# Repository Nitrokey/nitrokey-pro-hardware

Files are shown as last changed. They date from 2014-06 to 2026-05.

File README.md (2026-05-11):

Nitrokey Pro PCB Design
===================================================

Nitrokey Pro is a USB 32-bit computer with STM32F103 processor and
an OpenPGP smart card. It has a minimalistic design, the MCU is running
at 72MHz, and it has a SWD port for main flash ROM update.

This is Nitrokey PCB design for KiCAD, based on Niibe
Yutaka's Flying Stone Tiny 01 (FST-01).

Files
=====

    README:           This file
    BOM.csv           Part list including Digikey product number.
    ChangeLog:        History of this project
    cryptostick.pro:  Project file of KiCAD
    cryptostick.sch:  Schematic
    cryptostick.cmp:  Component
    cryptostick.net:  Netlist
    cryptostick.stf:  Component and Module
    cryptostick.brd:  PCB design
    library:          schematic library
    module:           footprint modules for PCB
    fabrication:      Gerber files of the PCB
    datasheet:        Datasheets of parts

Note that files under datasheet directory is copyrighted by vendors.

Revisions
=========

| Revision | MCU |
|---|---|
| 1 | ST STM32F103TB |
| 2 | ST STM32F103TB |
| 3 | ST STM32F103TB |
| 4 | ST 32F103B7 |
| 5 | GigaDevice GD32F103CB |
| 6 | ST STM32F103TB |

Terms and conditions
====================

This work is based on Niibe Yutaka's Flying Stone Tiny 01 (FST-01) PCB Design.

I would like to ask users to keep the design as "Open Hardware".  See
the page for the definition of "Open Hardware":
http://www.opencollector.org/Whyfree/open_hardware.html

Nevertheless, schematic design is distributed under Creative Commons
Attribution 3.0 Unported License (CC BY 3.0).  See:
http://creativecommons.org/licenses/by/3.0/

Schematic design can be used for any purpose and you don't need to
open your modifications to my design.

For PCB, it is distributed under Creative Commons
Attribution-ShareAlike 3.0 Unported (CC BY-SA 3.0).  See:
http://creativecommons.org/licenses/by-sa/3.0/

External modules
================

For module/SMT_CAP.mod and module/SMT_RES.mod, module drawings are
copied from w_smd_cap.mod and w_smd_resistors.mod by W.Lain.  Files
are available at:
http://smisioto.no-ip.org/elettronica/kicad/kicad-en.htm

Its copyright notice is like following:

> Kicad Library by W. Lain - kcswalter@member.fsf.org

> This library is released under the terms of the Creative Commons
license v3.0, Attribution-Share Alike.

> The author holds no responsibility for any damage that can be caused
by the usage of this library. You are however welcome to report any
error or discrepance to the author, provided that you give also the
correct information and its source (i.e. the correct datasheet).

> **Note that the author used publicly available data sheets from many
different companies, and that package dimensions, pin numeration and
schematic symbols may vary slightly between companies.**

Flashing
========

For instructions on flashing the device please have a look at the [Nitrokey Pro firmware
repo](https://github.com/Nitrokey/nitrokey-pro-firmware).

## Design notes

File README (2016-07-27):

Crypto Stick v1 PCB Design

							    Version 0.1
							     2014-01-17
						               Jan Suhr

Introduction
==============

Crypto Stick is a USB 32-bit computer with STM32F103 processor and
an OpenPGP smart card. It has a minimalistic design, the MCU is running
at 72MHz, and it has a SWD port for main flash ROM update.

This is Crypto Stick v1 PCB design for KiCAD, based on Niibe
Yutaka's Flying Stone Tiny 01 (FST-01).

Files
=====

    README:           This file
    BOM.csv           Part list including Digikey product number.
    ChangeLog:        History of this project
    cryptostick.pro:  Project file of KiCAD
    cryptostick.sch:  Schematic
    cryptostick.cmp:  Component
    cryptostick.net:  Netlist
    cryptostick.stf:  Component and Module
    cryptostick.brd:  PCB design
    library:          schematic library
    module:           footprint modules for PCB
    gerber:           Gerber files of the PCB
    datasheet:        Datasheets of parts

Note that files under datasheet directory is copyrighted by vendors.

Terms and conditions
====================

This work is based on Niibe Yutaka's Flying Stone Tiny 01 (FST-01) PCB Design.

I would like to ask users to keep the design as "Open Hardware".  See
the page for the definition of "Open Hardware":

    http://www.opencollector.org/Whyfree/open_hardware.html

Nevertheless, schematic design is distributed under Creative Commons
Attribution 3.0 Unported License (CC BY 3.0).  See:

    http://creativecommons.org/licenses/by/3.0/

Schematic design can be used for any purpose and you don't need to
open your modifications to my design.

For PCB, it is distributed under Creative Commons
Attribution-ShareAlike 3.0 Unported (CC BY-SA 3.0).  See:

    http://creativecommons.org/licenses/by-sa/3.0/

External modules
================

For module/SMT_CAP.mod and module/SMT_RES.mod, module drawings are
copied from w_smd_cap.mod and w_smd_resistors.mod by W.Lain.  Files
are available at:

   http://smisioto.no-ip.org/elettronica/kicad/kicad-en.htm

Its copyright notice is like following:
---------------------------------------------------------------------
Kicad Library by W. Lain - kcswalter@member.fsf.org

This library is released under the terms of the Creative Commons
license v3.0, Attribution-Share Alike.

The author holds no responsibility for any damage that can be caused
by the usage of this library. You are however welcome to report any
error or discrepance to the author, provided that you give also the
correct information and its source (i.e. the correct datasheet).

Note that the author used publicly available data sheets from many
different companies, and that package dimensions, pin numeration and
schematic symbols may vary slightly between companies.
---------------------------------------------------------------------

Flashing
========

This hardware can be flashed in two different ways:

* SWD protocol requires a separate programmer such as the ST-Link V2 (or cheaper clones). The SWD port or the Nitrokey PCB are the four blank contact points. You can either solder four wires or build your own adapter (see directory cs_pogo_adapter).

* A bit easier would be to use DFU. It requires a serial/TTL port (perhaps you need a serial/TTL-USB adapter) and a simple adapter. The DFU port is routed to the USB plug. Your adapter should consist of a USB socket which four pins are connected to your serial/TTL connector. The pinout is as follows.

Nitrokey USB Plug <-> Serial/TTL adapter

Pin 1, VCC <-> VCC
Pin 2, D-  <-> TX
Pin 3, D+  <-> RX
Pin 4, GND <-> GND

This diagram represents the pinout of the USB socket which you are going to solder:

  ################### 
  #                 # 
  # ############### # 
  #                 # 
  #                 # 
  ################### 
     #   #   #   #   
     #   #   #   #    

     1   2   3   4

To flash the firmware you need to bridge the two contact holes (e.g. with a wire) and only then connect (and power) the PCB to your adapter. The bridge triggers the hardware to boot into DFU mode. You may use [STM32 Flash Loader Demonstrator](http://www.st.com/content/st_com/en/products/development-tools/software-development-tools/stm32-software-development-tools/stm32-programmers/flasher-stm32.html) (Windows only) or the open source command line tool [stm32flash](http://stm32flash.sourceforge.net).

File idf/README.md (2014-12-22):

Creating IDF libraries
======================

Two files are needed to create an IDF library. An .emn and an .emp. 

* .emn: Holds information about the PCB board, the drilled holes and the placement of the parts.
* .emp: Holds information about each class of a component that is used at .emn placement.

To create a 3D model of the IDF library, you can open the .emn file using FreeCAD. Then you can save the 3D models as a .FCStd file.

The procedure of creating and manipulating an IDF library is explained below (per project).

Creating the .emp
-----------------
	The .emp file consists of a header section at the beginning. This sections is followed by electrical sections. Each electrical section has the outline info as a series of points in a 2D plane, and a height value. The outline must be a closed curve, thus you need to place twice the point that you started, once at the beginning and once at the end of the section (returning to starting point).
	If it is a rectangular outline, use point (0,0) as the center of it.

Creating the .emn
-----------------
	The .emn file consists of a header section, a board section, a drilled_holes section and a placement section. The board section describes the boad outline and height. The placement section is a series of placement declarations, each one declaring the type of the component (from .emp file), a placeholder name,  the positioning at the 3D plane, a rotation factor and the side of the board that is to be placed (top/bottom)

Nitrokey Pro
------------
	For Nitrokey Pro, you have to open the .kicad_pcb file. There is a section that lists all the modules. Each module has the component type (BOM file), the placeholder name (emp placement). the positioning and rotation (emp placement). 

You have to manually create/edit the .emp file consulting the BOM and manuals.
You have to manually create/edit the .emn file consulting the .kicad_pcb file for the placement coordinates.

*Note 1: Depending on the orientation of each component at it's electrical section, you may need to use rotation to match the real design.*

*Note 2: Depending on the side that the component is placed, you may have to calculate some offsets because the coords seems to be mirrored on the other side (and you have to mirror them again so that it aligns).*

Nitrokey Storage
----------------
	For Nitrokey Storage, you have to use DesignSpark. First you export the pcb design as a set of .idl and .idf files [3](without the height adjusting, see next par.) . Rename .idl to .emp and .idf to .emn (they are essentially the same format).
	You will have to manually edit the .emp file to include all the electrical sections (consulting the BOM, manualls and naming of the components from the .emn file).  The .emn file doen't need any changes.

Notes (on Storage):
1) Right now the height of the short capacitors and resistors is not accurate. An approximation is used instead (worst case found from the family of each component).
2) For some components the length does not include the extra soldering area.
3) Electrical sections for the R0603, C0603, C0603K and C1206 need to be rewritten with (0,0) as their center. Also their orientation at the placement section need to be changed appropriatelly. 

For both devices
----------------
	Create a second module to model USB.

Useful Links
------------
[1] https://www.simplifiedsolutionsinc.com/images/idf_v30_spec.pdf
[2] https://sourceforge.net/projects/kicad-3d/
[3] http://www.rs-online.com/designspark/electronics/eng/tutorial/exporting-designs-from-designspark-pcb-to-mechanical-cad

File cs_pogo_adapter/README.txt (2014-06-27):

J8 and J9 are different types of pads used on different target PCBs. They are all connected together to make testing easier.

R1 and R2 are required depending on whether you use Versaloon or ST-Link programmer.

R1 is used to power the target device when using ST-Link. ST-Link doesn't provide power to the target board normally, but it has 3.3V on pin 19 of the JTAG connector (which is normally not connected on the target board).

R2 is used to power the target device when using Versaloon. I think Versaloon can power the target through pin 1 of the JTAG connector, but I'm not sure.

J4 and J7 are obsolete and should be removed.

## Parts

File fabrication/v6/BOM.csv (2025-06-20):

Id | Designator | Package | Quantity | Designation | Digikey Part Number | Digikey URL
1 | JP1 | boot | 1 | JUMPER | n.a.
2 | P1 | SIL-2-2 | 1 | CONN_4 | n.a.
3 | C3,C7,C6,C5,C4,C8 | c_0402 | 6 | 0.1uF | No tantalum, tolerance 20%, temperature -20 to +70 °C. | http://www.digikey.com/product-detail/en/C1005X7R1C104M050BC/445-4953-1-ND/2093567
4 | R1,R2 | r_0402 | 2 | 510 | 1% tolerance, temperature -20 to +70 °C. | http://www.digikey.com/product-detail/en/RC0402FR-07510RL/311-510LRCT-ND/729579
5 | C1,C2 | c_0402 | 2 | 27pF | No tantalum, tolerance 20%, temperature -20 to +70 °C. | http://www.digikey.com/product-detail/en/C1005C0G1H270J050BA/445-1240-1-ND/567721
6 | C9,C11 | c_0402 | 2 | 4.7uF | No tantalum, tolerance 20%, temperature -20 to +70 °C. | http://www.digikey.com/product-detail/en/C1005X5R1A475M050BC/445-8023-1-ND/2792141
7 | U2 | TSOT23-5 | 1 | CAT6217-330 | 576-2835-1-ND or ADP121-AUJZ33R7CT-ND | http://www.digikey.com/product-detail/en/MIC5265-3.3YD5%20TR/576-2835-1-ND/1821995
8 | U1 | QFN36 | 1 | STM32F103TB | 497-11534-ND | http://www.digikey.com/product-search/en?vendor=0&keywords=497-11534-ND
9 | X1 | ABM8G | 1 | 12MHz | 535-10283-1-ND | http://www.digikey.com/product-detail/en/ABM8G-12.000MHZ-B4Y-T/535-10283-1-ND/2218096
10 | R3,R4 | c_0402 | 2 | 10k | 1% tolerance, temperature -20 to +70 °C. | http://www.digikey.com/product-detail/en/RC0402FR-0710KL/311-10.0KLRCT-ND/729470
11 | C10 | c_0402 | 1 | 0.01uF | No tantalum, tolerance 20%, temperature -20 to +70 °C. | http://www.digikey.com/product-detail/en/C1005X7R1E103K050BB/445-1260-1-ND/567737
12 | U3 | SOT-553 | 1 | DF5A5.6JE | DF5A5.6JELMCT-ND | https://www.digikey.com/products/en?keywords=DF5A5.6JELMCT-ND
13 | J2 | USB-A-PLUG | 1 | USB_A | WM3983TR-ND | http://www.digikey.com/product-detail/en/0480372200/WM3983CT-ND/2421836
14 | D1 | KPHBM-2012SURKCGKC | 1 | DUAL_LED | element14.com 1686079RL | http://www.digikey.com/product-detail/en/APHBM2012SURKCGKC/754-1093-1-ND/1747810
15 | J1 | Molex 0786463001 | 1 | SIM_JACKET | WM9364CT-ND | http://www.digikey.com/product-detail/en/0786463001/WM9364CT-ND/3770350
16 | R7 | r_0402 | 1 | 1.5k | 311-1.50KLRCT-ND | https://www.digikey.com/product-detail/en/yageo/RC0402FR-071K5L/311-1.50KLRCT-ND/729466
17 | R5,R6 | r_0402 | 2 | 22 | 311-22.0LRCT-ND | https://www.digikey.com/product-detail/en/yageo/RC0402FR-0722RL/311-22.0LRCT-ND/729509
18 | R8 | r_0402 | 1 | 20k | 311-20.0KLRCT-ND | https://www.digikey.de/de/products/detail/yageo/RC0402FR-0720KL/726557

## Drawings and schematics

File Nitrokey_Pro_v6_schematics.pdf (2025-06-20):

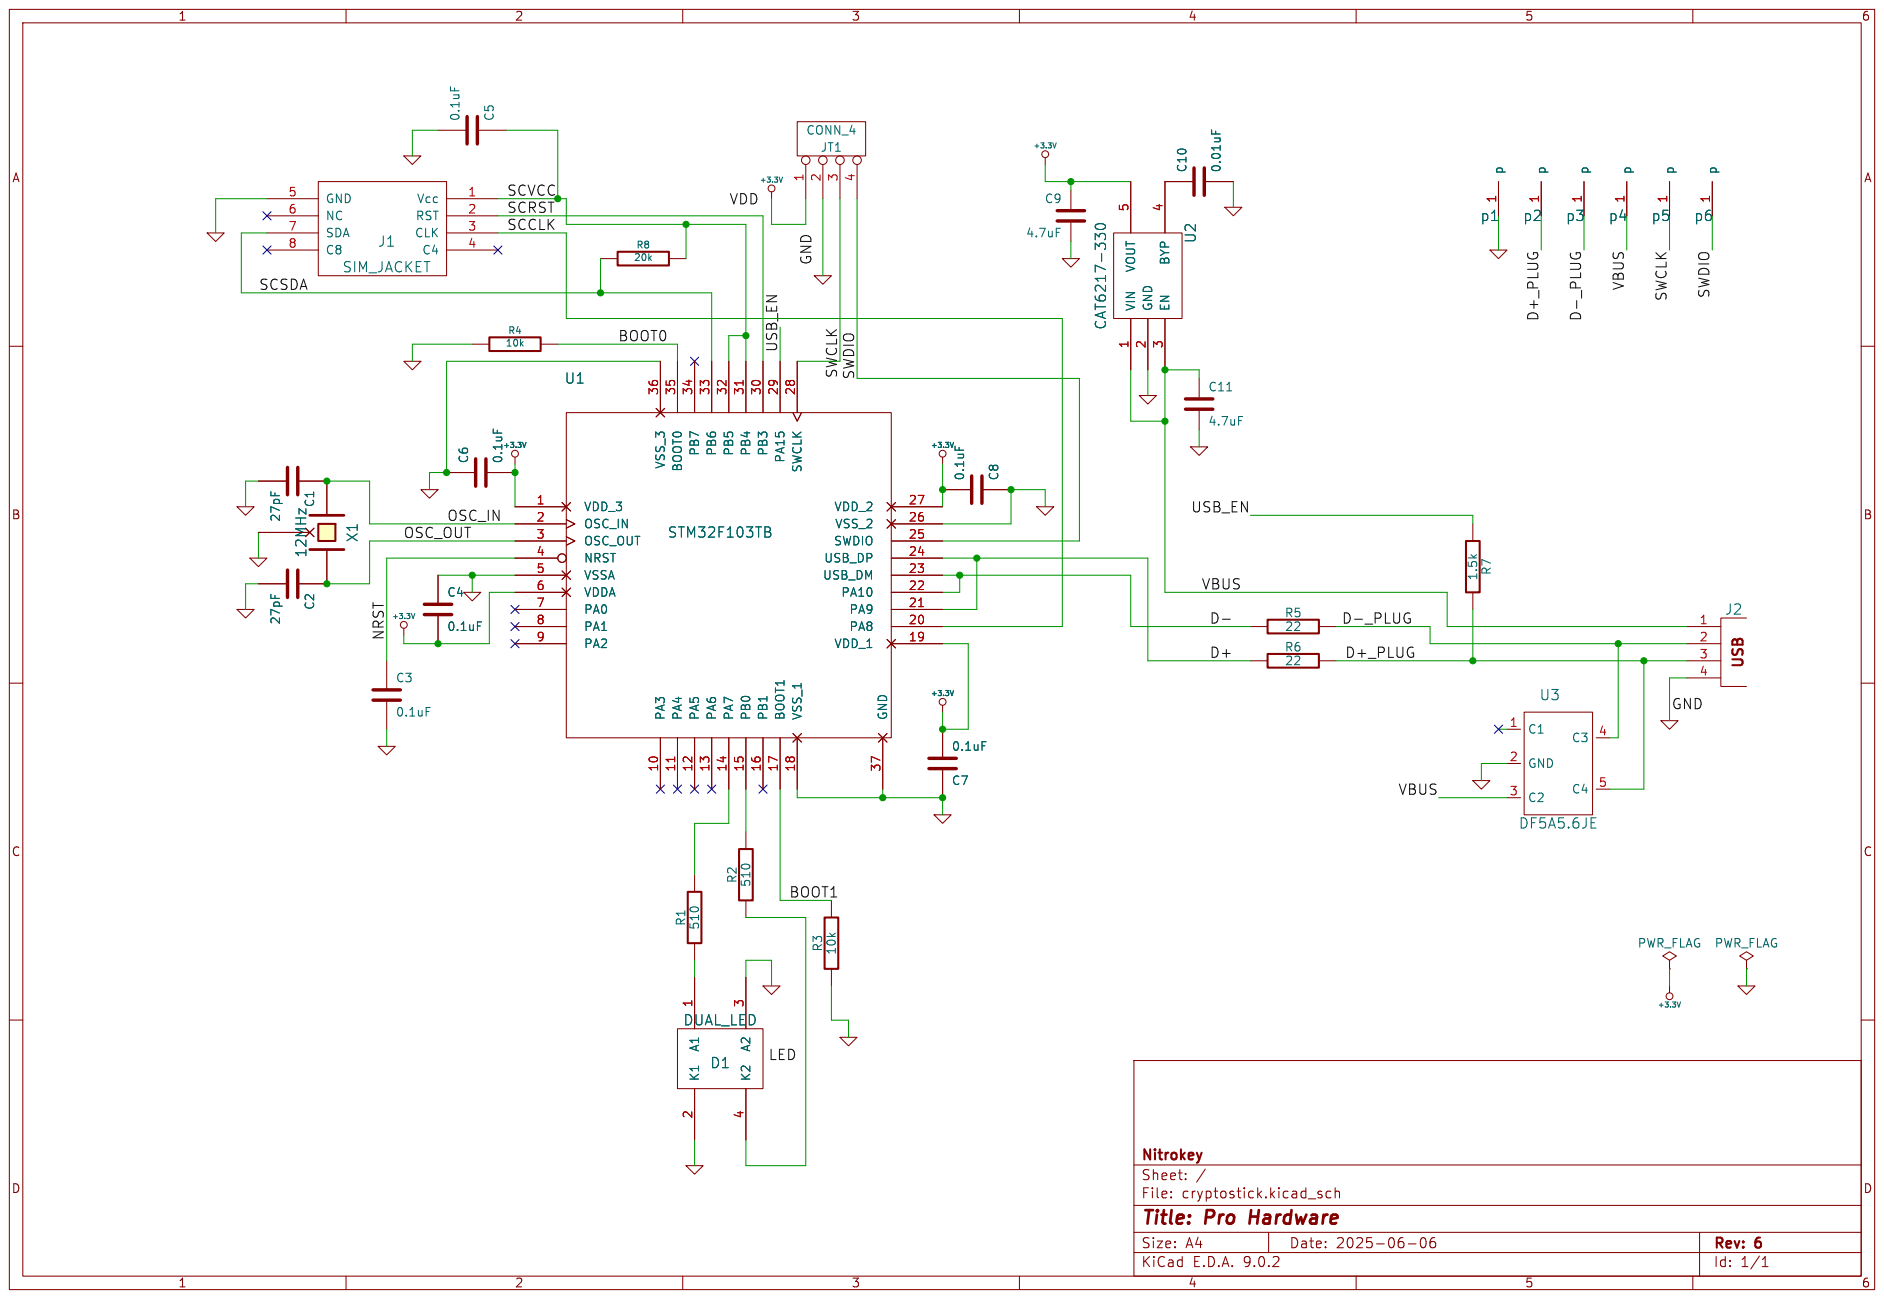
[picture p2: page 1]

Id: 1/1 Title: Pro Hardware

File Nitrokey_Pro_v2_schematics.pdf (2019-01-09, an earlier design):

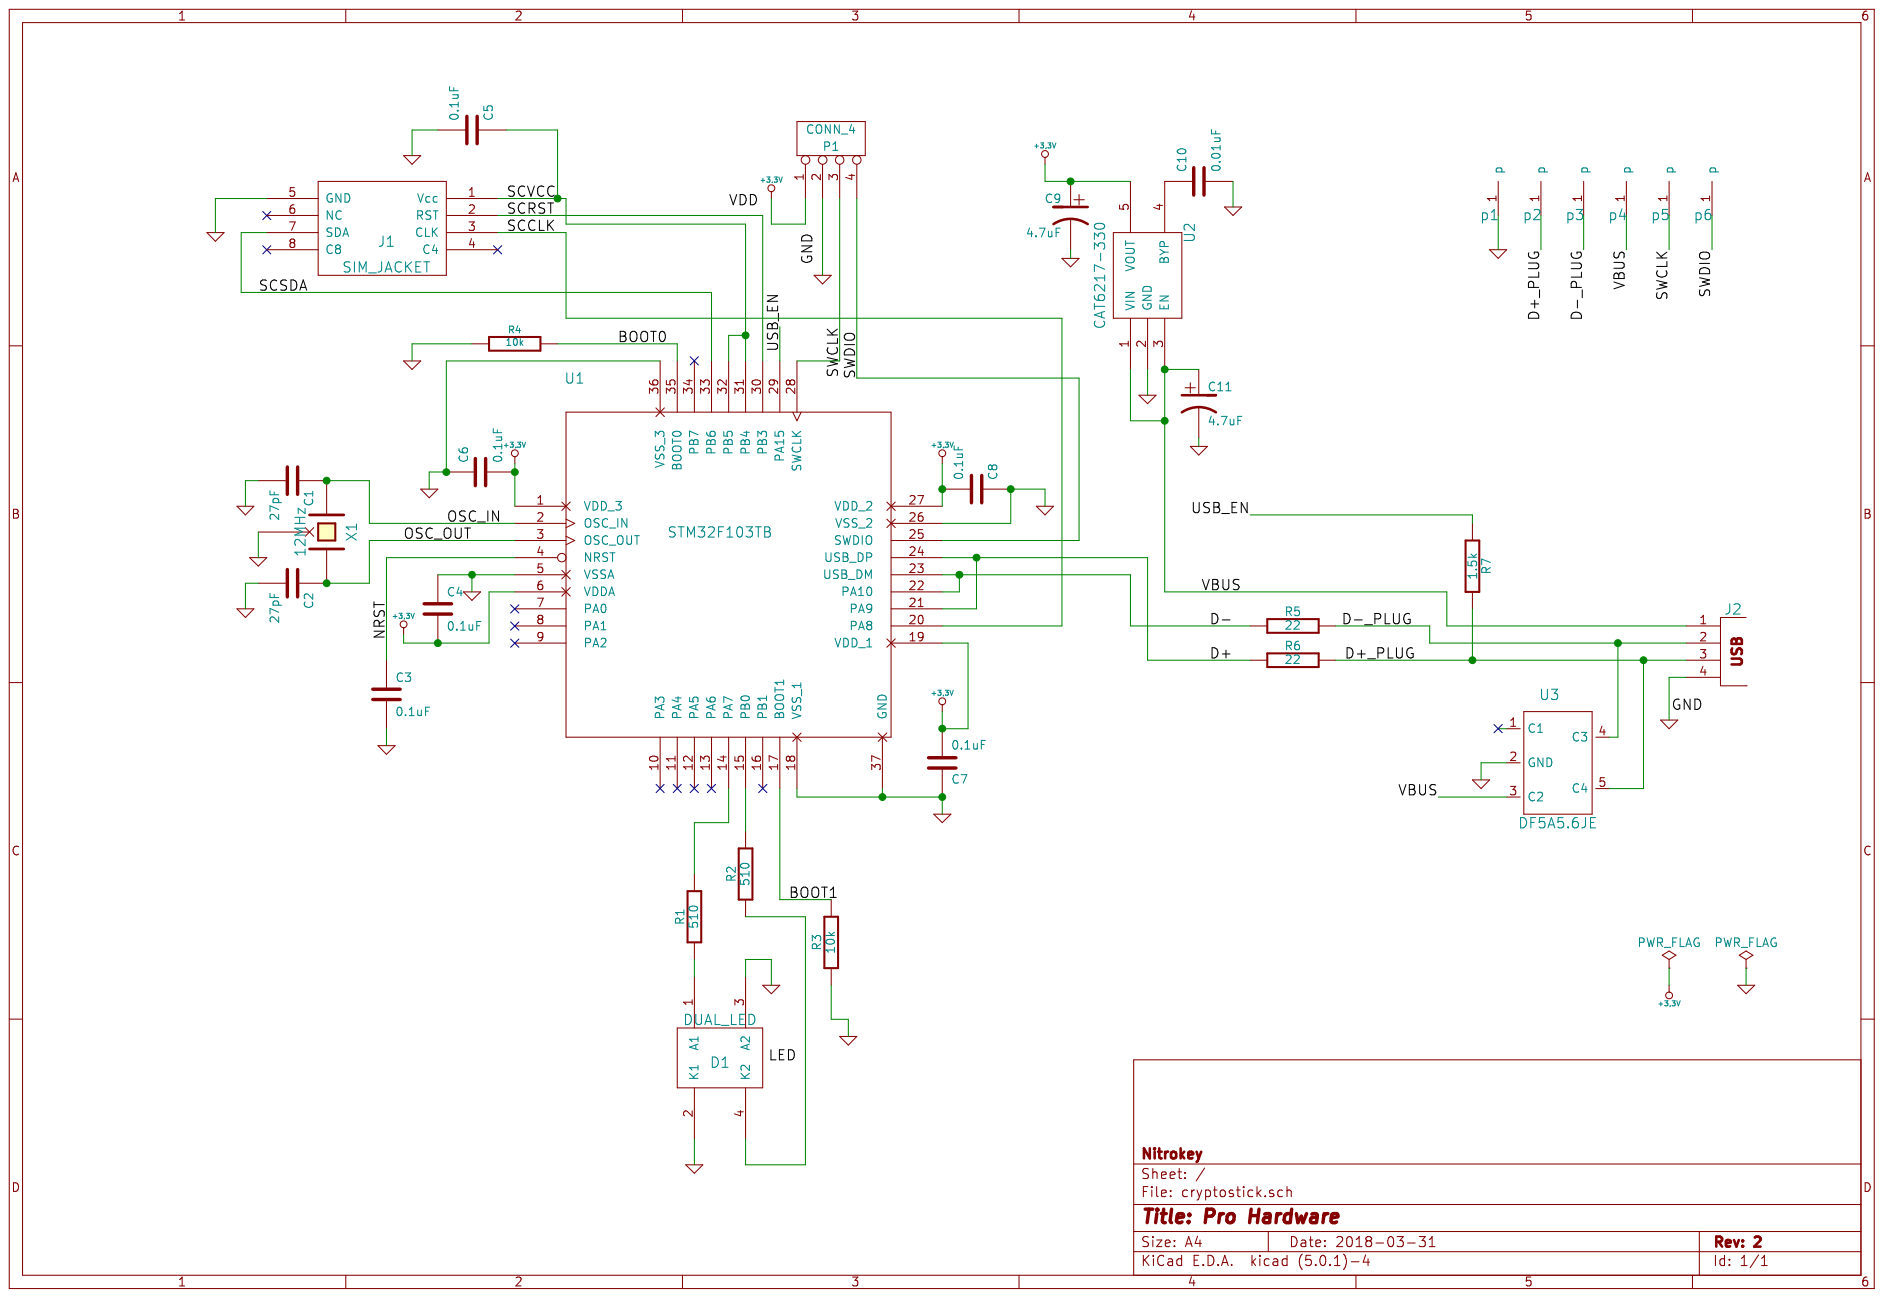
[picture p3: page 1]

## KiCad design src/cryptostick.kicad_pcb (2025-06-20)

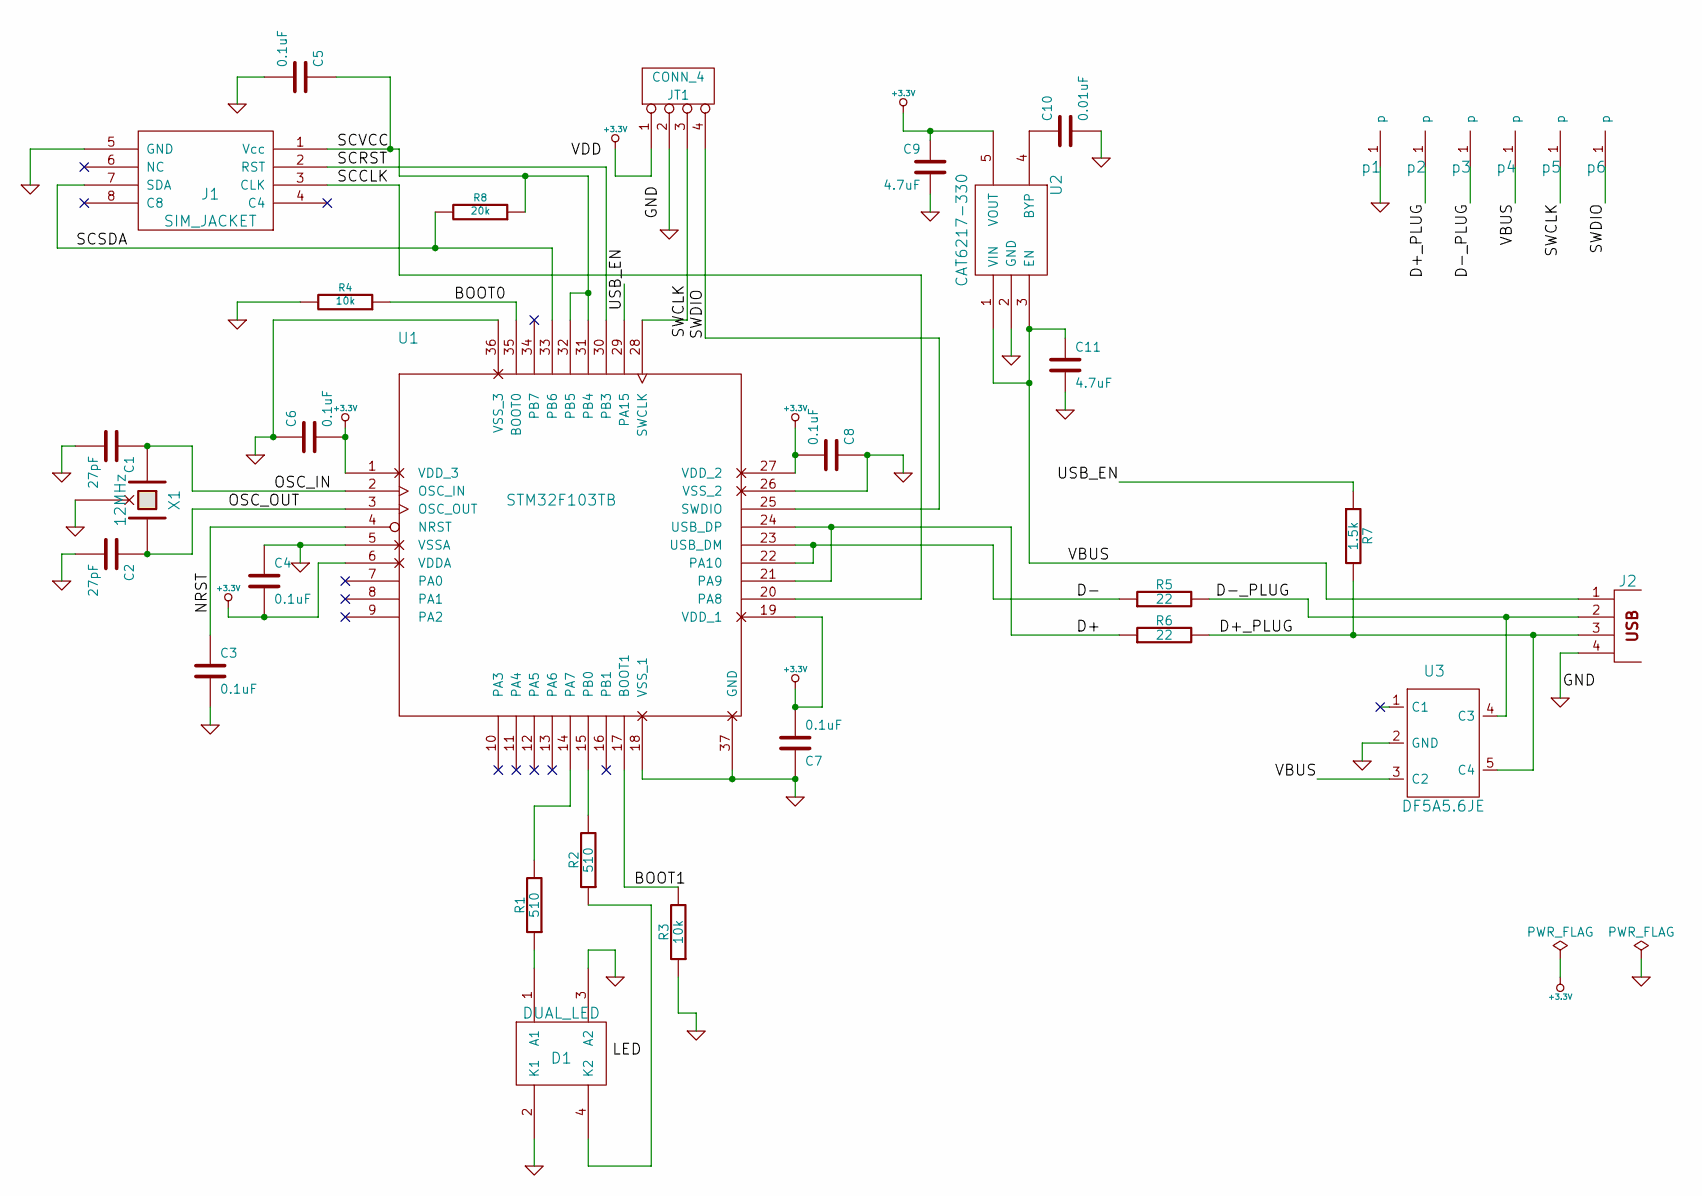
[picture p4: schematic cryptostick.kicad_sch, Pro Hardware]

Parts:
C1, C2: 27pF; C_0402_1005Metric
C3, C4, C5, C6, C7, C8: 0.1uF; C_0402_1005Metric
C9, C11: 4.7uF; C_0402_1005Metric
C10: 0.01uF; C_0402_1005Metric
D1: DUAL_LED; KPHBM-2012SURKCGKC
J1: SIM_JACKET; molex 78646-3001
J2: USB_A; USB-A-PLUG
JT1: CONN_4; SIL-2-2-drilled-offset
R1, R2: 510; R_0402_1005Metric
R3, R4: 10k; R_0402_1005Metric
R5, R6: 22; R_0402_1005Metric
R7: 1.5k; R_0402_1005Metric
R8: 20k; R_0402_1005Metric
U1: STM32F103TB; QFN-36-1EP_6x6mm_P0.5mm_EP4.1x4.1mm_ThermalVias
U2: CAT6217-330; TSOT-23-5
U3: DF5A5.6JE; SOT-553
X1: 12MHz; ABM8G
p1, p2, p3, p5, p6: debug-pin; Prog_Pad_Circular
p4: PROG_VCC; Prog_Pad_Circular

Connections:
+3.3V: C4.2, C6.2, C7.2, C8.2, C9.1, JT1.1, U1.1 (VDD_3), U1.6 (VDDA), U1.19 (VDD_1), U1.27 (VDD_2), U2.5 (VOUT)
/BOOT0: R4.1, U1.35 (BOOT0)
/BOOT1: R3.2, U1.17 (BOOT1)
/D+: R6.1, U1.21 (PA9), U1.24 (USB_DP)
/D+_PLUG: J2.3, R6.2, R7.2, U3.5 (C4), p2.1 (p)
/D-: R5.1, U1.22 (PA10), U1.23 (USB_DM)
/D-_PLUG: J2.2, R5.2, U3.4 (C3), p3.1 (p)
/NRST: C3.1, U1.4 (NRST)
/OSC_IN: C1.1, U1.2 (OSC_IN), X1.1
/OSC_OUT: C2.1, U1.3 (OSC_OUT), X1.2
/SCCLK: J1.3 (CLK), U1.20 (PA8)
/SCRST: J1.2 (RST), U1.30 (PB3)
/SCSDA: J1.7 (SDA), R8.2, U1.33 (PB6)
/SCVCC: C5.1, J1.1 (Vcc), R8.1, U1.31 (PB4), U1.32 (PB5)
/SWCLK: JT1.3, U1.28 (SWCLK), p5.1 (p)
/SWDIO: JT1.4, U1.25 (SWDIO), p6.1 (p)
/USB_EN: R7.1, U1.29 (PA15)
/VBUS: C11.1, J2.1, U2.1 (VIN), U2.3 (EN), U3.3 (C2), p4.1 (p)
GND: C1.2, C2.2, C3.2, C4.1, C5.2, C6.1, C7.1, C8.1, C9.2, C10.2, C11.2, D1.2 (K1), D1.3 (A2), J1.5 (GND), J2.4, JT1.2, R3.1, R4.2, U1.5 (VSSA), U1.18 (VSS_1), U1.26 (VSS_2), U1.36 (VSS_3), U1.37 (GND), U2.2 (GND), U3.2 (GND), X1.3 (GND), p1.1 (p)
unnamed: D1.1 (A1), R1.1
unnamed: D1.4 (K2), R2.1
unnamed: R1.2, U1.14 (PA7)
unnamed: R2.2, U1.15 (PB0)
unnamed: C10.1, U2.4 (BYP)

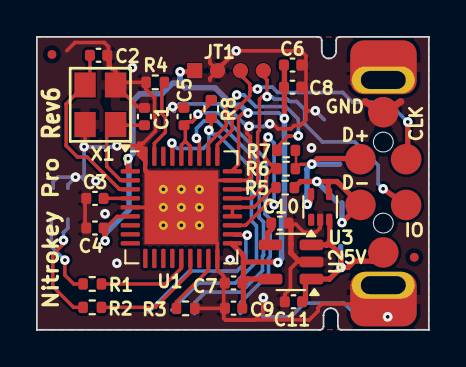
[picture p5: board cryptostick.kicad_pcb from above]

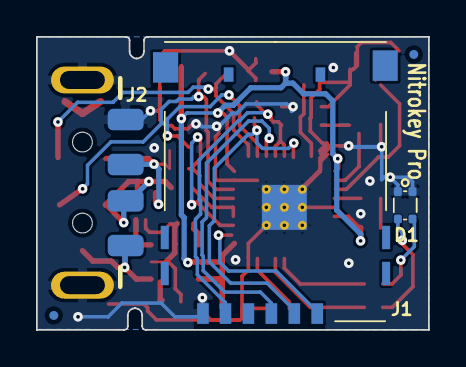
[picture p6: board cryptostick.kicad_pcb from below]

Board: 2 copper layers, 21.8 x 16.3 mm, 37 parts (5 on the bottom side), 24 nets.

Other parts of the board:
FID1, FID2, FID3, FID4: Fiducial_0.5mm_Dia_1mm_Outer

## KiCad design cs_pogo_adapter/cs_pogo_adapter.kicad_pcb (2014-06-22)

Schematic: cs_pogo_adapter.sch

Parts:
J1, J5, J6: HEADER_6
J2: HEADER_10X2
J3, J4, J7, J8, J9: HEADER_4
R1: 0

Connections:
+3.3V: J2.19, R1.1
/SWCLK: J1.4, J2.9, J3.3, J4.3, J5.4, J6.4, J7.3, J8.3, J9.3
/SWIO: J1.5, J2.7, J3.4, J4.4, J5.5, J6.5, J7.4, J8.4, J9.4
/TVCC: J2.1; also elsewhere on the board
GND: J1.3, J2.12, J2.18, J2.20, J3.2, J4.2, J5.3, J6.3, J7.2, J8.2, J9.2
VCC: J1.2, J3.1, J4.1, J5.2, J6.2, J7.1, J8.1, J9.1, R1.2; also elsewhere on the board

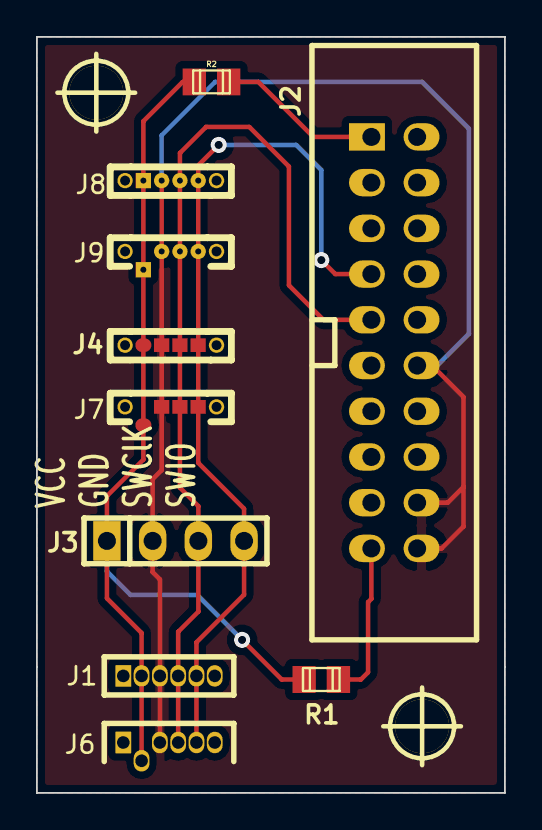
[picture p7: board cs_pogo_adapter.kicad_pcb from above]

Board: 2 copper layers, 26.0 x 42.0 mm, 10 parts (0 on the bottom side), 6 nets.

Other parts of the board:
R2: 0; r_0805

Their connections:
/TVCC: R2.1; also elsewhere on the board
VCC: R2.2; also elsewhere on the board

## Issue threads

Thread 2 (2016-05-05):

HW button to confirm signature/key access

breznak, 2016-05-05:
Hello,

I'm comparing your NitroKey to `Yubikey2` HW, where I'd like to prefer your solution, mainly for it's OSS _both_ HW & SW, and that it's made in Germany.

I missing feature I find is that yubikey has a HW button that needs to be pressed to confirm action each time the donge is to be used. Why is this missing in NitroKey? Would you plan to implement it in future generations?

jans23, 2016-05-06:
The reason is, that its significant effort. We will consider a button for the next major revision but its not decided and not planned yet.

breznak, 2016-05-06:
..Ok, thanks for considering. You might want to make a poll about requested features. I introduced NitroKey to a local community and the lack of manual confirmation was the most often raised concern.

jans23, 2016-05-06:
Was it kind of hacker and IT-pro community?

lrvick, 2016-05-17:
Huge +1 on this. It is the only blocker for rolling out Nitrokeys instead of Yubikeys in my organization.

aharonh, 2018-02-04:
+1 for this from here as well. What would otherwise prevent malicious software from using my keys without my intention? Taking the key in-and-out each time makes the probability to loose the key significantly higher, and as there is no implementation of internal key-duplication (as far as I understand) that puts the credentials/data/money in real danger. I'd be glad to learn that I am missing something in the work-flow with the key that disproves the point above.

breznak, 2018-02-06:
> Was it kind of hacker and IT-pro community?

Both hacker/privacy people, but importantly also corporate

mfp20, 2020-02-18:
Same issue here: I'd prefer Nitrokey becouse of its strong OSS commitment ... but find it useless without a button independent from the host. In my case I'd like to have it connected to my desktop keyboard's usb port, so to have it handy each time I need to use it; and have to unplug only when my (usually day-long) session ends.

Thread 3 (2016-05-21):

Are these the port-audit schematics?

ColinGilbert, 2016-05-21:
Hi,

I read the audit at https://cure53.de/pentest-report_nitrokey.pdf and the https://www.nitrokey.com/news/2015/nitrokey-storage-got-great-results-3rd-party-security-audit.

Do these schematics reflect changes made to fix the issues raised?

jans23, 2016-05-22:
The audit applies to Nitrokey Storage. See https://github.com/Nitrokey/nitrokey-storage-hardware and https://github.com/Nitrokey/nitrokey-storage-firmware

Closed 2016-05-22.

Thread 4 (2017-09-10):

Storage time until loss of data

MauroMombelli, 2017-09-10:
I'm planning to keep my nitrokey without power for a long amount of time, probably more than a year. Is there any risk to loose the stored keys?
If there is, what is the suggested storage time between recharge?
How long will the battery be reliable?

jans23, 2017-09-11:
Hi! The Nitrokey doesn't contain a battery and therefore there is no risk of loosing your data/keys when keeping it offline for a few years.

MauroMombelli, 2017-09-11:
Thanks for the answer, but can you please clarify how data is storage?
AFAIK flash memory will decade? Is this subject to magnetic field? Is safe
to keep the key in a metal box? What if someone pass a strong magnet over
it? What if I keep the sealed box outside (-15 in winter, 40+ in summer)?

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

jans23, 2017-09-11:
Usually, magnetic fields and extreme temperatures won't be a problem for you.

Keys are stored in a smart card which is actual EEPROM storage. The specified storage duration is more than 20 years. Regarding magnetic field you find some information [here](https://superuser.com/questions/395876/is-flash-storage-affected-by-magnetic-fields) and [here](https://forums.anandtech.com/threads/should-smartcards-be-affected-by-magnetic-fields.2056204/) for example. A higher temperature **during operation** may decrease its life endurance. For example Microchip has some [good details](http://ww1.microchip.com/downloads/en/AppNotes/01019A.pdf) (although this is not a Microchip product). Extreme temperatures during offline storage shouldn't be a problem.

MauroMombelli, 2017-09-11:
I think this should be placed somewhere in the description page of the
product, it is quite impressive, and important information for an user.

Thanks for clarification, this exceed my expectation :)

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

Closed 2017-09-11.

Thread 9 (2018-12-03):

Nitrokey Pro v2 Flashing

23pieces, 2018-12-03:
I recently got a Nitrokey Pro v2 and was just trying to flash it.
Unfortunately the Layout has changed and there are no jumper holes on v2.
Is there a PCB Layout and a circuit diagram for v2?
Does v2 run the same firmware as v1?

I tried to get it running on Win 1809 but i need to flash the new firmware to get it running.

Best regards
23pieces

23pieces, 2018-12-03:
Hey!

Maybe you should write somewhere on your page that v2 cannot be flashed over UART anymore only over SWD.

szszszsz, 2019-01-04:
Hi @23pieces!
Added a note about this in https://github.com/Nitrokey/nitrokey-pro-hardware/commit/720867c59360547e96b16a76fa12997f46a66fe0

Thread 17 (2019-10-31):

80+ DRC error: a toolchain issue or a feature?

biergaizi, 2019-10-31:
I want to do some minor modification of the board for testing. Unfortunately, under KiCad 5.0.2, a DRC check of  `cryptostick.kicad_pcb` reports more than 80 errors, including vias clearance issues and items on disabled layers. Should I worry about them? Are these errors here by design, or is it a problem in my toolchain?

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

jans23, 2019-11-04:
The DRC is not set correctly. Unfortunately KiCad does not always take over the DRC settings correctly. You have to set the minimum track width to 0.15 mm and DuKo to 0.2 mm. Then there should be 8 problems left, all checked and accepted manually.

biergaizi, 2019-11-06:
> You have to set the minimum track width to 0.15 mm and DuKo to 0.2 mm.

Sorry, I don't understand the situation. What you've description was in total contradiction with the code. `cryptostick.kicad_pcb` specifies that,

```
  (setup
    (last_trace_width 0.127)
    (trace_clearance 0.127)
    (zone_clearance 0.15)
    (zone_45_only no)
    (trace_min 0.127)
    (segment_width 0.15)
    (edge_width 0.09906)
    (via_size 0.5461)
    (via_drill 0.381)
    (via_min_size 0.5461)
    (via_min_drill 0.381)
    (uvia_size 0.50038)
    (uvia_drill 0.14986)
    (uvias_allowed no)
    (uvia_min_size 0.50038)
    (uvia_min_drill 0.14986)
    (pcb_text_width 0.3048)
    (pcb_text_size 1 2)
    (mod_edge_width 0.09906)
    (mod_text_size 0.8 0.9)
    (mod_text_width 0.15)
    (pad_size 0.3048 0.3048)
    (pad_drill 0.3)
    (pad_to_mask_clearance 0.05)
    (solder_mask_min_width 0.05)
    (pad_to_paste_clearance_ratio -0.1)
    (aux_axis_origin 127 98.9965)
    (grid_origin 119.76 98.05)
    (visible_elements 7FFFE67F)
    (pcbplotparams

 (net_class GND ""
    (clearance 0.20066)
    (trace_width 0.20066)
    (via_dia 0.5461)
    (via_drill 0.381)
    (uvia_dia 0.50038)
    (uvia_drill 0.14986)
    (add_net GND)
  )

  (net_class VBUS ""
    (clearance 0.20066)
    (trace_width 0.20066)
    (via_dia 0.8001)
    (via_drill 0.59944)
    (uvia_dia 0.50038)
    (uvia_drill 0.14986)
  )

  (net_class VDD ""
    (clearance 0.1524)
    (trace_width 0.1524)
    (via_dia 0.5461)
    (via_drill 0.381)
    (uvia_dia 0.50038)
    (uvia_drill 0.14986)
    (add_net +3.3V)
  )
```

None of the settings match your description. the code says the the minimum track width is 0.127mm for default nets, 0.20mm for Gnd and VBus, and 0.15mm for Vdd. It also says the minimum vias is 0.5461mm.

Is the layout file broken?

jans23, 2019-11-06:
I don't know the internals of cryptostick.kicad_pcb but the settings look different to me.

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

biergaizi, 2019-11-07:
This is strange.

Are you sure all the changes have been committed to this repository? I was working on git master, commit faa33253b8036cea5b7442066949f93d5b731546, and this is what I see here...

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

jans23, 2019-11-07:
These are default settings which you can set according to your needs. Ideally, change it as suggested above. These settings affect the amount of errors shown to you and affect future changes of the layout.

Agree, it would be nice to have these default settings in the repository correct. We try to fix it in the next revision.

BTW, it looks like you use not the latest version of you layout.

biergaizi, 2019-11-10:
faa3325 is the latest commit in the master branch. Where can I find the latest version of the layout?

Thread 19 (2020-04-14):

Possibly redundant resistors on the USB data lines

szszszsz, 2020-04-14:
It is possible the 22 Ohm resistors on the USB data lines are redundant, due to misleading reference schematics. To investigate.

A report from one of the users received on Riot:
> I am watching some videos about USB, one seems to tell that 22 r resistors on the USB data lines are not needed
https://youtu.be/vwlXUOY7KY0?t=269
They are on the Nitrokey_Pro_v2_schematics.pdf, and I think I saw them on other board designs
That seemed weird, but why not. Then I saw the video suggesting that a "reference" design included them without mentioning it was a workaround because an improper ESD part was used

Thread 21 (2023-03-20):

Lifetime expectation

milouse, 2023-03-20:
Hi,

I’m an happy user of a nittrokey pro from 2016. Recently I began to encounter some glitches (the key "block" indefinitely with red led up and fix until I unplug it and plug it again). They make me wonder how many time a nitrokey is expected to last? As I use it to encrypt a lot of my secret (including some encrypted harddrive), losing it without notice is not really an option. Thus I’m wondering if it’s time to think about a new one or if normally they are built to last 20-30 year?

Thank you very much.

jans23, 2023-03-20:
From the [factsheet](https://www.nitrokey.com/files/doc/Nitrokey_Pro_factsheet.pdf):

* Life expectancy (MTBF, MTTF): >100,000 PIN entries
* Durability USB connector (EIA-364-09): >1,500 mate and unmate cycles
* Storage time: >20 years

szszszsz, 2023-03-20:
Hi!
This might be a symptom of a known firmware issue: https://github.com/Nitrokey/nitrokey-pro-firmware/issues/54.
In case the locking issue does not happen when only the smart card services are used, then I would say it is expected as of the current state.
I believe the numbers provided by Jan are correct in practice. I have not broken my devices yet as well. Nevertheless, please keep in mind to have key backups (in the cold storage or on other Nitrokeys) for any cases of the hardware failure (so it would not become the single point of failure in your system setup).

Closing as done. Please reopen if that does not answer your question.

milouse, 2023-03-20:
Thank you very much for your answers! I reassure you I regularly do some backup. But my question was more to be prepared about switching properly from one key to a new one while the older is still working, instead of being obliged to make an emergency purchase/delivery of a new one and restart from backup once the old one die ;)

I might already have crossed https://github.com/Nitrokey/nitrokey-pro-firmware/issues/54, but the current behavior only involved the smartcard alone (i.e. hang on decrypting something after some inactivity). That said, I also wonder if it could not be related to a general OS update (like gpg or the smartcard being lost after a suspend?). I’ll watch in the near future how it evolves.

Closed 2023-03-20.

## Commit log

2014-01-17 initial version
    [BOM.csv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]
2014-02-27 New PCB layout. Changed programming connector. Added uart to USB connector. Moved LED to other side.
    [cryptostick_new.brd]
2014-03-02 Changed boot0 jumper to THT. Decreased VDD via size.
    [BOM.csv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]
2014-03-02 Cleaning repo.
    [cryptostick_6mil.brd, cryptostick_new.brd]
2014-03-03 Updated BOM with Digikey links
    [BOM.csv]
2014-03-07 Fixed silkscreen.
    [cryptostick-B_Mask.gbs, cryptostick-B_Paste.gbp, cryptostick-B_SilkS.gbo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]
2014-06-22 Added programmer adapter baord project.
    [$cs_pogo_adapter.sch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]
2014-06-25 USB plug updated
    [BOM.csv]
2014-11-03 Keystone USB plug removed
    [BOM.csv]
2014-11-25 slots for lands of casing added
    [cryptostick-B_Mask.gbs, cryptostick-B_Paste.gbp, cryptostick-B_SilkS.gbo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]
2014-12-04 LED moved and 3D model added
    [$cs_pogo_adapter.sch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]
2014-12-22 USB plug shifted and tolerances added to IDF
    [cryptostick-B_Mask.gbs, cryptostick-B_Paste.gbp, cryptostick-B_SilkS.gbo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]
2015-01-08 slots resized from 1mm to 0.7mm
2015-01-27 pitch of programmer pads changed; slots changed to 0.7mm
    [cryptostick-B_Mask.gbs, cryptostick-B_Paste.gbp, cryptostick-B_SilkS.gbo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]
2015-04-08 resize pcb, moved usb plug
2015-04-27 0.5mm longer
    [BOM.csv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]
2015-04-27 extended PCB by 0.5mm
2017-12-06 Pads under USB provided
    USB connection exposed as pin pads, similarly how we did it at the last
    hardware (FIDO U2F)
    [cryptostick.kicad_pcb, cryptostick.sch]
2018-03-31 DRC errors have been fixed on the original design:
    - gnd power source has been added
    - conflicted pin types changed to bidirectional
    [cryptostick.sch]
2018-04-04 V2
    - ESD protcetion IC changed from NUF221W1 to DF5A5.6JE
    - USB terminating and enable resistors have been added
    - USB connector footprint has been corrected
    - Many duplicated footrpints and tracks have been deleted
    - GND plane on TOP side mistakenly wasnt connected to GND net.
    Corrected.
    - Fabrication files have been updated
    - JP1 DFU selector jumper has been deleted
    [BOM.csv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]
2018-12-11 Add connector drawing and flashing description
2018-12-21 ticks added
    [cryptostick-B.Mask.gbs, cryptostick-B.Paste.gbp, cryptostick-B.SilkS.gbo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]
2019-01-10 Fix Connector layout and add note about data loss (#14)
    * Correct pinout of Debug connector add note about data loss when flashing
    * make connector drawing smaller
    * make connector drawing smaller
    * Add stylized USB connector for reference
2019-01-25 Corrections of fabrication data
    [cryptostick-B.Mask.gbs, cryptostick-B.Paste.gbp, cryptostick-B.SilkS.gbo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]
2019-02-01 Pick & place files updated
    [cryptostick-all-pos.csv, cryptostick-bottom-pos.csv, cryptostick-top-pos.csv]
2025-06-20 Nk Pro v6 (#22)
    - update to KiCad v9
    - add smartcard pullup (R8)
    - update panelization
    - update outputs
    [BOM.csv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]
